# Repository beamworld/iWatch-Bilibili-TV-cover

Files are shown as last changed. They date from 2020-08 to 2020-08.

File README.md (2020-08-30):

# 请注意！！！本项目已迁移至[码云](https://gitee.com/beamworld/iWatch-Bilibili-TV-cover)，github不再更新，最新更新请到码云获取。

# iWatch-Bilibili-TV-cover
	本项目为手表iWatch的Bilibili小电视外壳，目前适用于桌面放置使用。功能如下：

1. 三个按键引出；
2. 耳机通孔引出；
3. Micro USB充电孔引出；
4. 屏幕开孔；

	**上美图~**

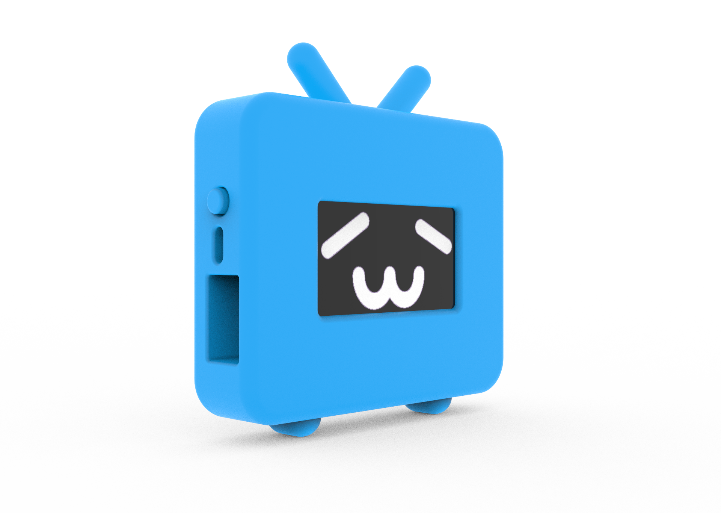
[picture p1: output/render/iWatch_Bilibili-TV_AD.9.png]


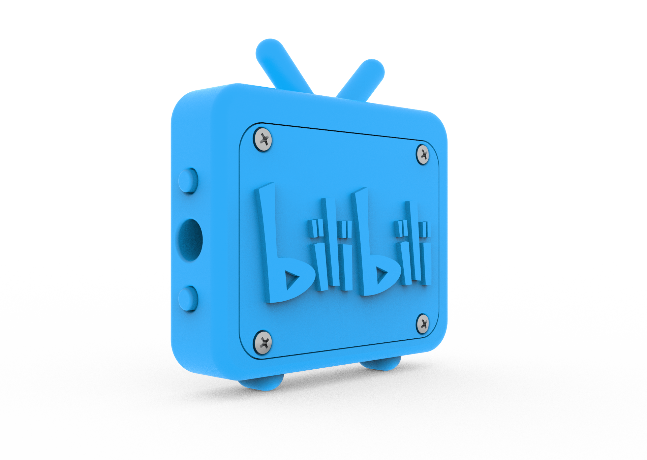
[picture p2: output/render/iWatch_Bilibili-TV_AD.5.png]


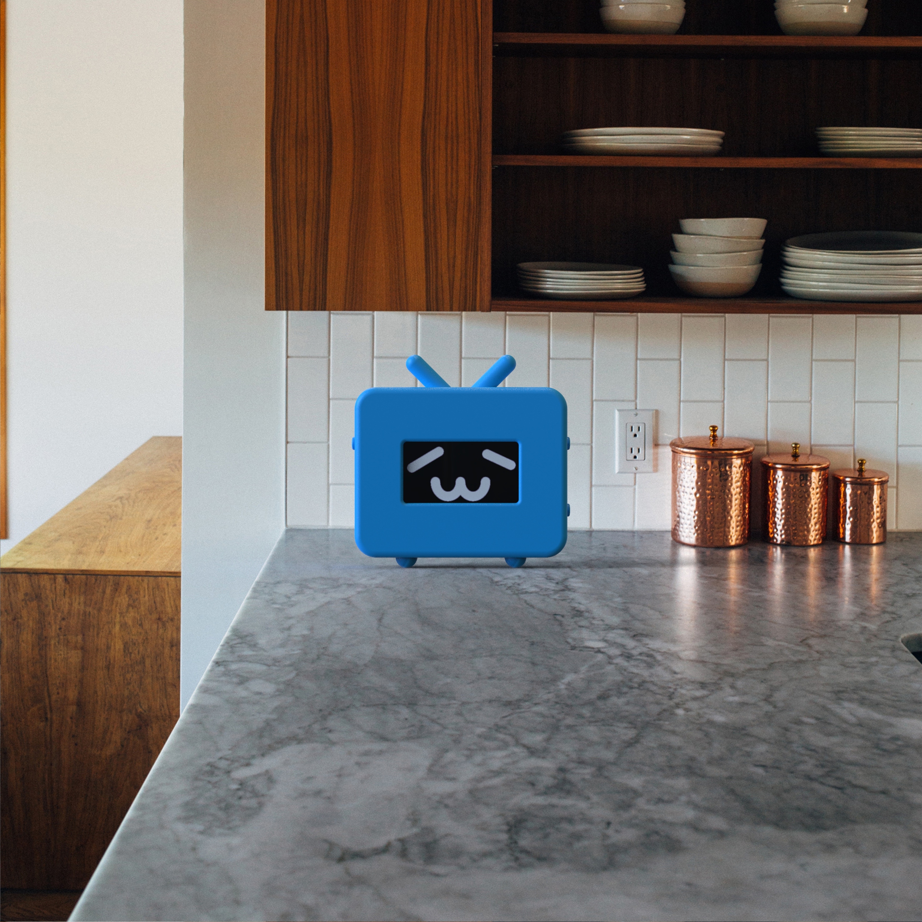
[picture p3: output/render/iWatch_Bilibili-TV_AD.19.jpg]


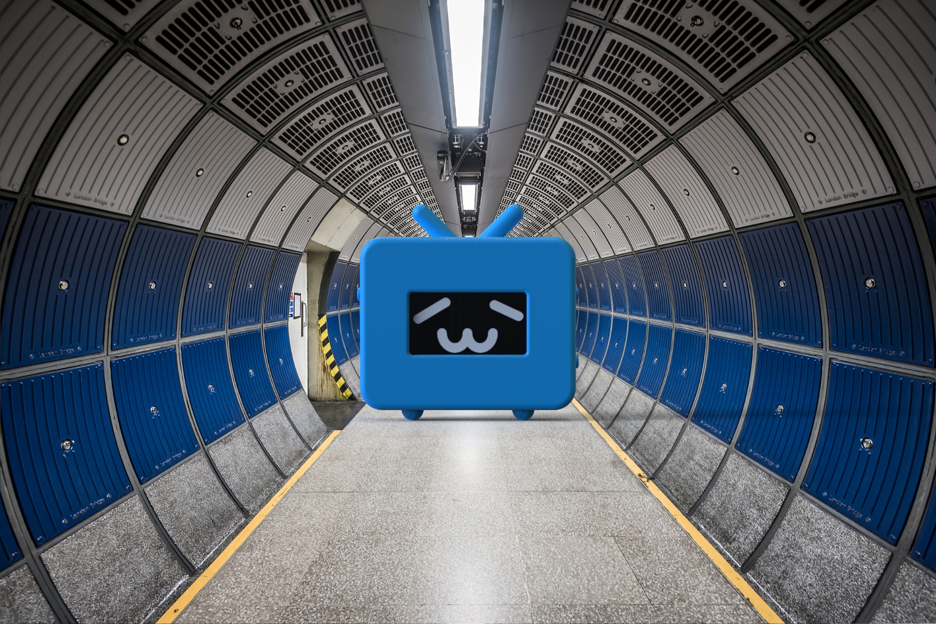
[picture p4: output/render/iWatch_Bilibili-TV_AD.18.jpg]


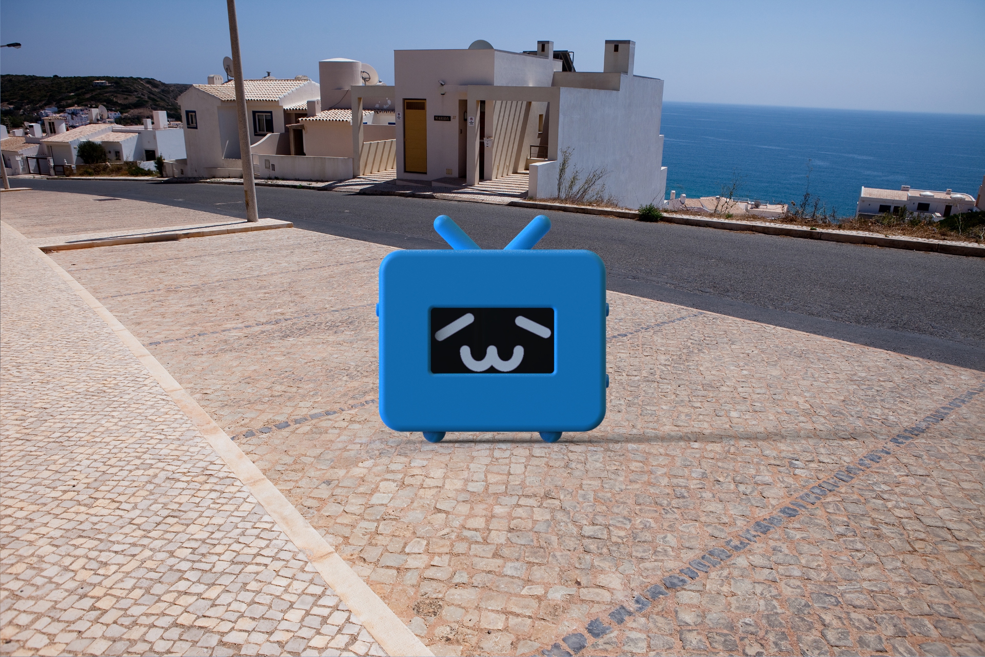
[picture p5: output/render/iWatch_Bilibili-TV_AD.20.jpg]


	又增加了一款手表外壳（Thin-cover），可以佩戴在手上。功能如下：

1. 三个按键引出；
2. 耳机通孔引出；
3. Micro USB充电孔引出；
4. 屏幕开孔；
5. 露出表带安装孔；便于安装表带；
6. 露出充电指示灯和照明灯；
7. 超薄机壳，厚度13mm。

	**上美图~**

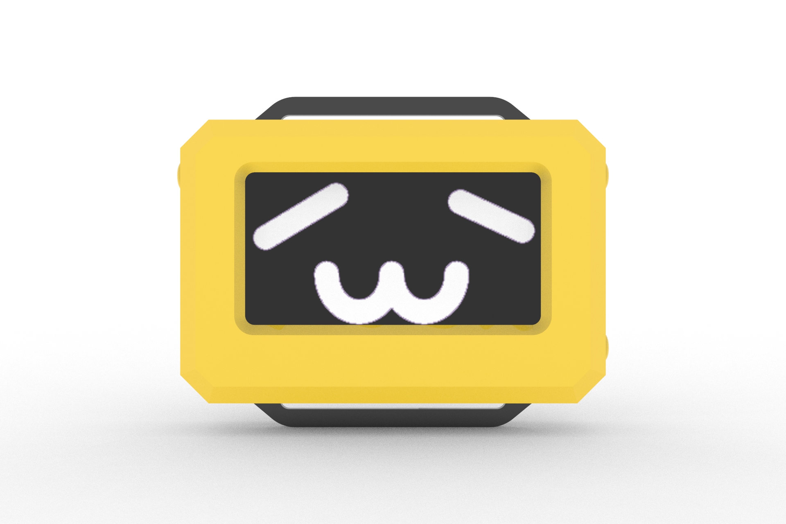
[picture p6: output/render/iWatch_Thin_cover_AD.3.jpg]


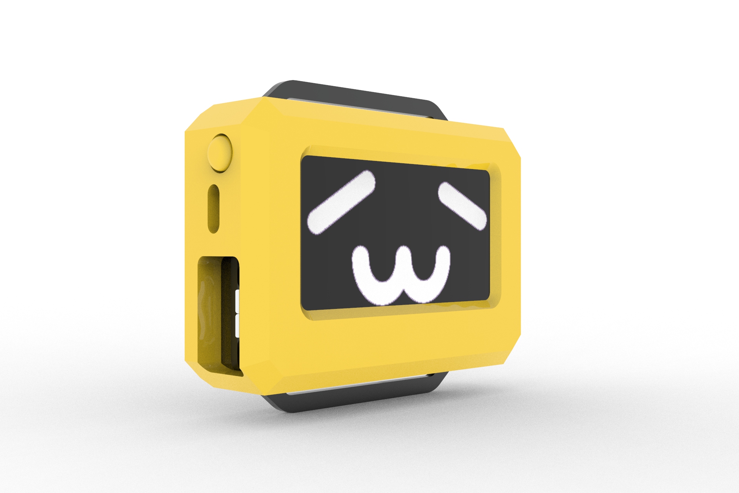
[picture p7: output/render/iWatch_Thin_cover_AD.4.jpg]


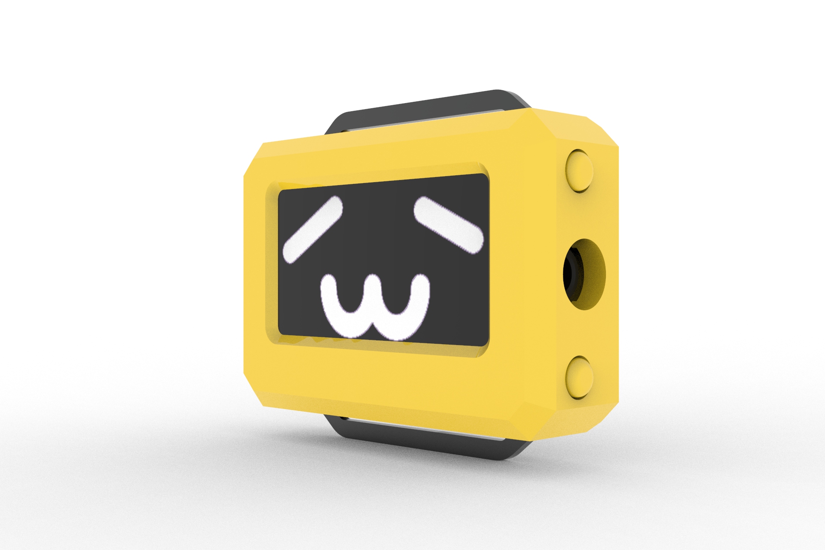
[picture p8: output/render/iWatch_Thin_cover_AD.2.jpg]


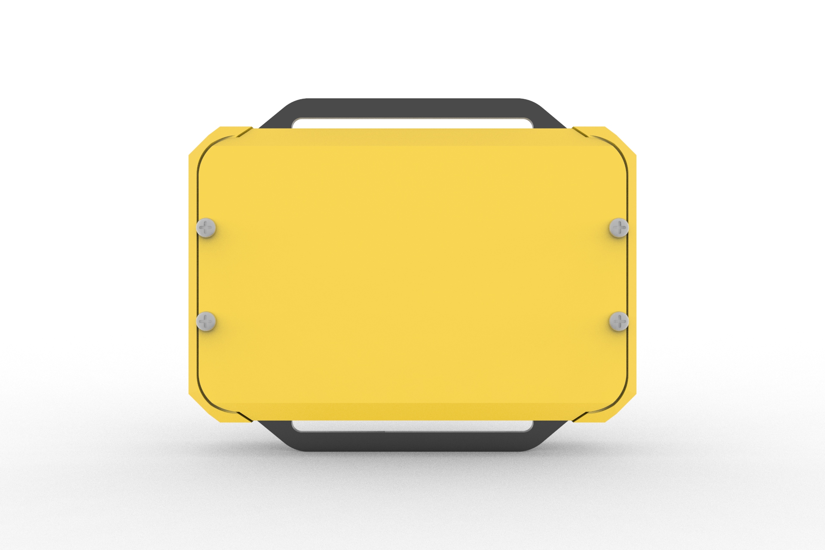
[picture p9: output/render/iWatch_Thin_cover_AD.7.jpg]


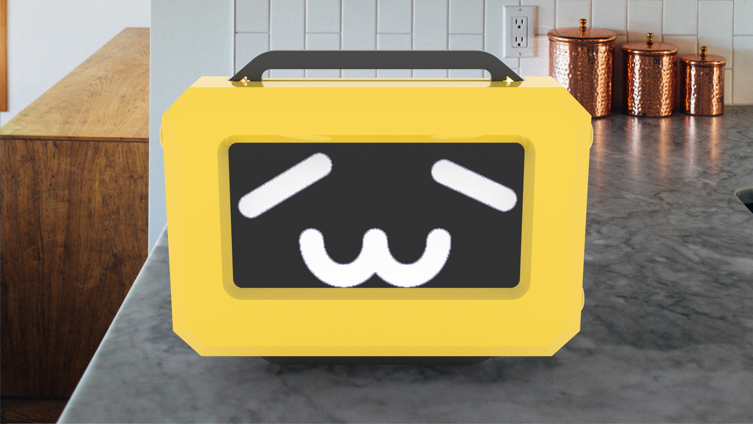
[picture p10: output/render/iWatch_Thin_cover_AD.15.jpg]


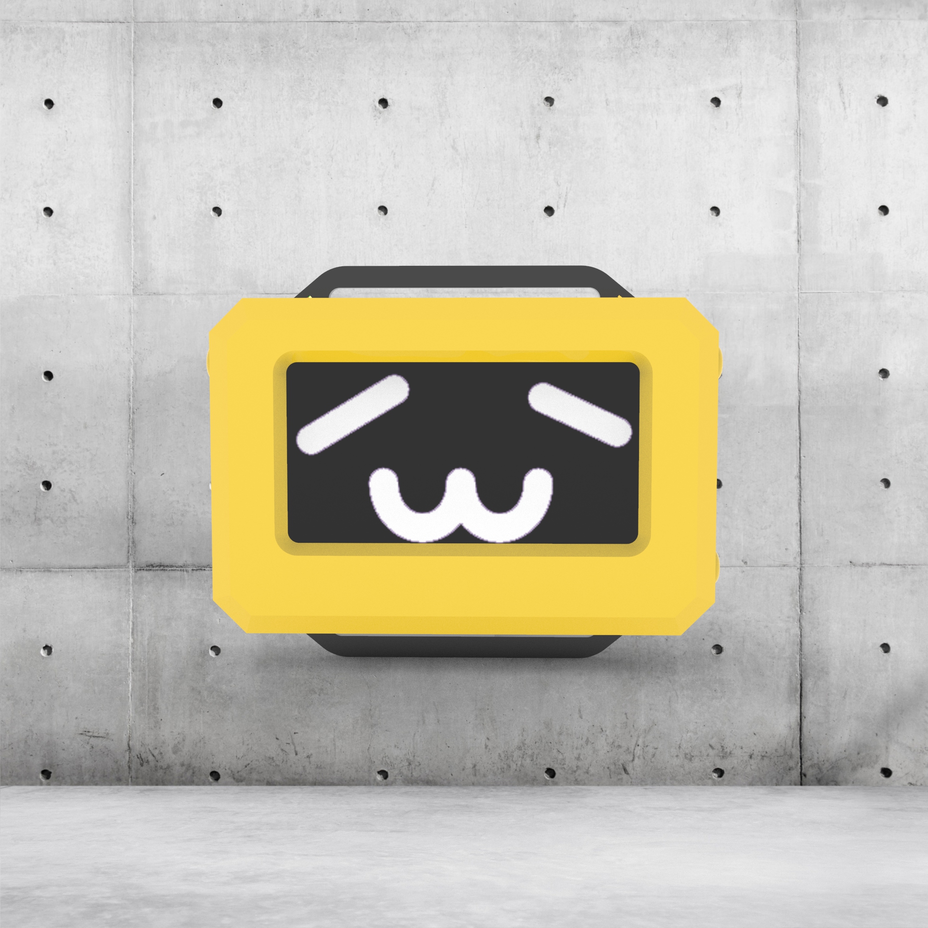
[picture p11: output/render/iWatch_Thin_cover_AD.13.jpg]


## 更新日志

`2020.08.18`

- [x] 测量并绘制iWatch。
- [x] 绘制元器件。
- [x] 组装渲染。
- [x] 获得CXC发来的AD导出STEP。

`2020.08.19`

- [x] 使用STEP重绘板型。
- [x] 组装渲染。
- [x] 绘制part1，part2，part3。
- [x] 修复屏幕露白边问题。
- [x] 修复孔位不对齐问题。
- [x] 修复iWatch-main-board和iWatch-screen-board同时打开会导致板型重载问题。
- [x] 后盖加入Bilibili标识。
- [x] 螺丝改为沉孔设计。
- [x] 整体加厚以保证安全。
- [x] 四边改为等宽增加美观。
- [x] 加入小电视美腿。
- [x] 增大MicroUSB开孔。
- [x] Keyshot渲染出图。
- [x] 加深按键开槽，解决按键太紧问题。
- [x] 加长电视腿，期望解决站不住问题。
- [x] 增大螺丝孔以抵消PLA的热膨胀。
- [x] 加厚前面板，以解决面板太薄露出黑色阴影。

`2020.08.20`

- [x] 增大后盖螺丝孔至2.6以适配更多打印机。
- [x] 新增手戴超薄机壳。

`2020.08.21`

- [x] 加深按键孔。
- [x] 增长按键。
- [x] 内部加入上下倒角，修复因太薄打印出现断开问题。
- [x] 修正小电视外壳充电口不是很准的问题。

## Bilibili-cover 3D打印使用方法

### 第一步：

	直接使用切片软件将[STL模型](https://github.com/beamworld/iWatch-Bilibili-TV-cover/tree/master/output/stl)切片为Gcode，然后再3D打印机上打印即可。需要打印的文件和数量如下。

| 模型名称 | 打印数量 | 用途 |
| :---: | :---: | :---: |
| Bilibili_part1.STL | 1 |  主外壳  |
| Bilibili_part2_cap.STL | 3 | 三个按键 |
| Bilibili_part3.STL | 1 | 后盖 |

**注意：1.Bilibili_part1.STL小电视天线部分需要打印支撑，否者你会获得一个烂电视或者破盒子。**

			**2.打印时不要打印任何类型的平台附着，会很很难刮。**

### 第二步：

	采购螺丝`M2x6盘头十字`四个用于安装后盖。或者你能借到，或者你能把什么拆了都行。

### 第三步：

1. 先把三个按键放到电视上对应孔中。
2. 放入iWatch。
3. 垫上一款减震棉在后盖和电池之间，减震棉你可以在你iWatch的快递盒子里找到，或者你再拆点什么。
4. 拧上4颗螺丝，拧的时候慢慢来，一开始可能不好进入，多蹭蹭~。（螺丝孔使用的是公差配合设计，所以不要整天把螺丝拆下来拧上去，会越来越松！）
5. 享受你的小电视吧。

**#有时间的话会搞一个安装教程----------------------------------------------------明年。**

## 工程指引

**#有时间的话会搞----------------------------------------------------明年。**

## Thin-cover 3D打印使用方法

### 第一步：

	直接使用切片软件将[STL模型](https://github.com/beamworld/iWatch-Bilibili-TV-cover/tree/master/output/stl)切片为Gcode，然后再3D打印机上打印即可。需要打印的文件和数量如下。

| 模型名称 | 打印数量 | 用途 |
| :---: | :---: | :---: |
| Thin_cover_part1.STL | 1 |  主外壳  |
| Thin_cover_part2_cap.STL | 3 | 三个按键 |
| Thin_cover_part3.STL | 1 | 后盖 |

**注意：1.打印时不要打印任何类型的平台附着，会很很难刮。**

### 第二步：

	采购螺丝`M1.2x3盘头十字`四个用于安装后盖。或者你能借到，或者你能把什么拆了都行。

### 第三步：

1. 先把三个按键放到机壳上对应孔中。
2. 放入iWatch。
3. 垫上一款减震棉在后盖和电池之间，减震棉你可以在你iWatch的快递盒子里找到，或者你再拆点什么。
4. 拧上4颗螺丝，拧的时候慢慢来，一开始可能不好进入，多蹭蹭~。（螺丝孔使用的是公差配合设计，所以不要整天把螺丝拆下来拧上去，会越来越松！）
5. 像平常一样安装表带。
6. 享受你的新表壳吧吧。

**#有时间的话会搞一个安装教程----------------------------------------------------明年。**

## 机械开发注意

1. PCB模型各边不是垂直，不确定是绘制PCB时就是如此还是后期导出所致。
2. 由STEP导出的模型转换为sldasm后，iWatch-main-board和iWatch-screen-board同时打开会导致板型重载为先打开的一个，不确定导致问题的原因，但通过导出sldpart解决。

## 友情链接

暂无其他相关开源

**#有时间的话会搞一个Bilibili相关固件给iWatch------------------------------------------明年。**

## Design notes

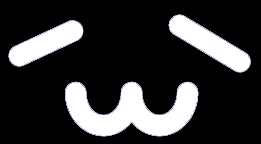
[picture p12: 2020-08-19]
source/image/face_inverted.png

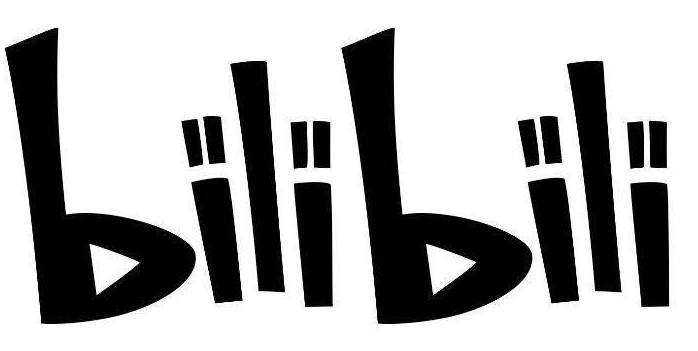
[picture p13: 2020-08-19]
source/image/bilibili.jpg

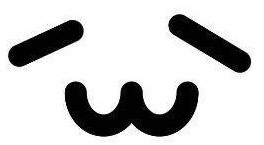
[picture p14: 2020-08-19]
source/image/face.jpg

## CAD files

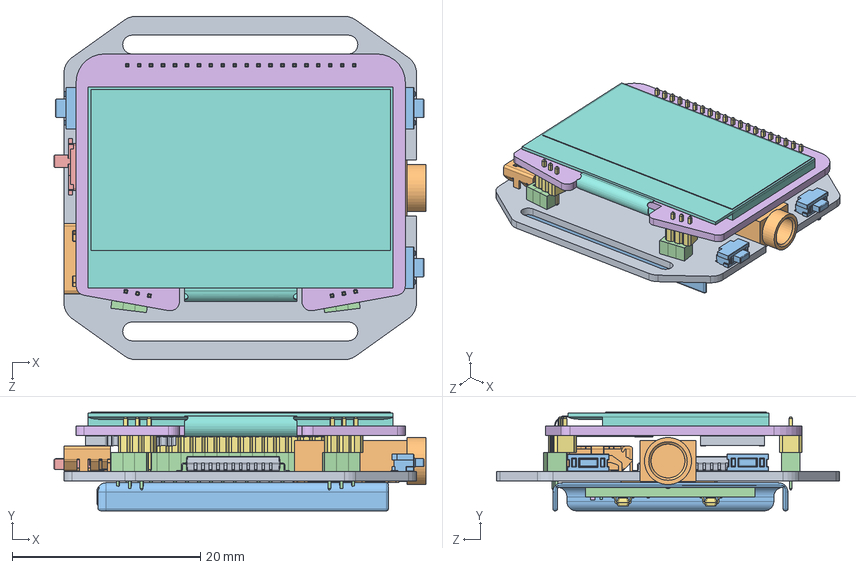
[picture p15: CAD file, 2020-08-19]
assembly/iWatch_unit_measure.SLDASM
39.5 x 10.5 x 36.5 mm
bottom_board
Phone_jack_PJ327A_5P_SMT
Battery_31x25mm_200mAh_3.7V_Li_cell
Battery_protection_board
0201_R
0402_R
SOT23-6 x 2
0201_C
STC51
MicroUSB_SMT
Button_2x4mm_Side_SMT x 3
Female-header_1.27mm_single_2mm-high x 26
Switch_mini_5x3mm_SPDT_Side_SMT
top_board
Male-header_1.27mm_single_2mm-high x 26
1.3inch_OLED
bluetooth_board

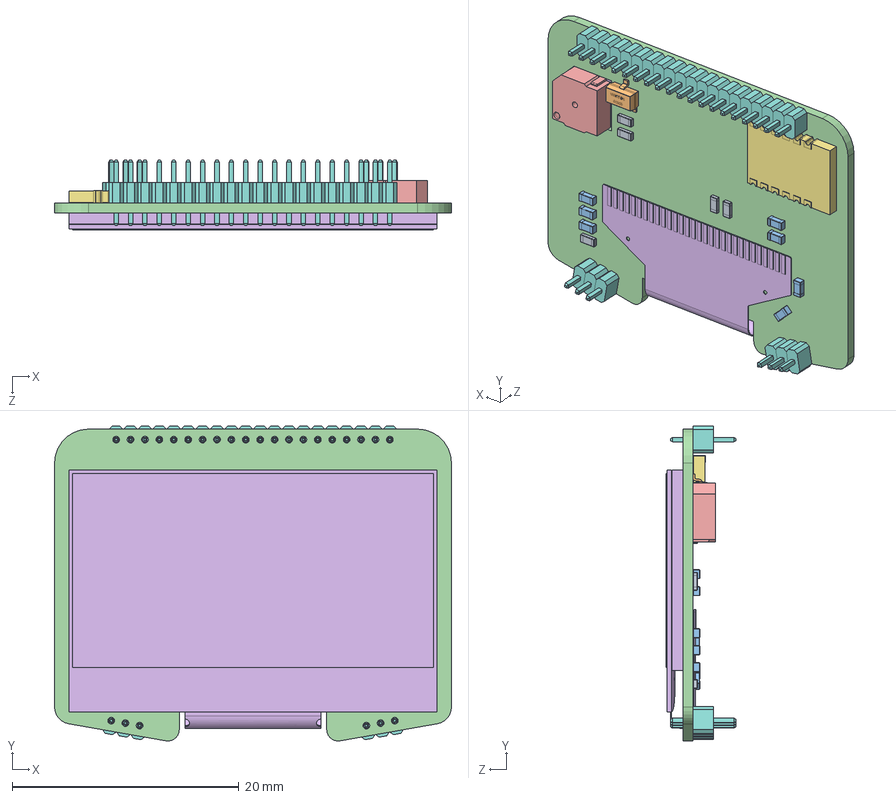
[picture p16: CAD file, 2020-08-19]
partial_assembly/iWatch-screen-board.SLDASM
35.0 x 27.8 x 6.19 mm
RESC1608(0603).step x 5
SOT-23.step
CAPC1608(0603).step x 7
Board.step
Beep_5020_SMT
1.3inch_OLED
bluetooth_board
Male-header_1.27mm_single_2mm-high x 26

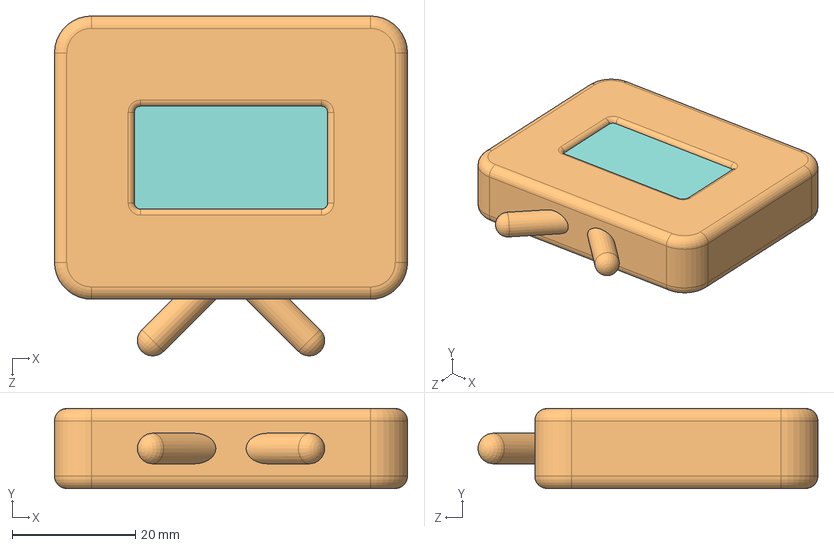
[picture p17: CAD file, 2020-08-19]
assembly/iWatch_Bilibili-TV_measure.SLDASM
57.3 x 13.0 x 55.2 mm
bottom_board
Phone_jack_PJ327A_5P_SMT
Battery_31x25mm_200mAh_3.7V_Li_cell
Battery_protection_board
0201_R
0402_R
SOT23-6 x 2
0201_C
STC51
MicroUSB_SMT
Button_2x4mm_Side_SMT x 3
Female-header_1.27mm_single_2mm-high x 26
Switch_mini_5x3mm_SPDT_Side_SMT
top_board
Male-header_1.27mm_single_2mm-high x 26
1.3inch_OLED
bluetooth_board
Bilibili_part1

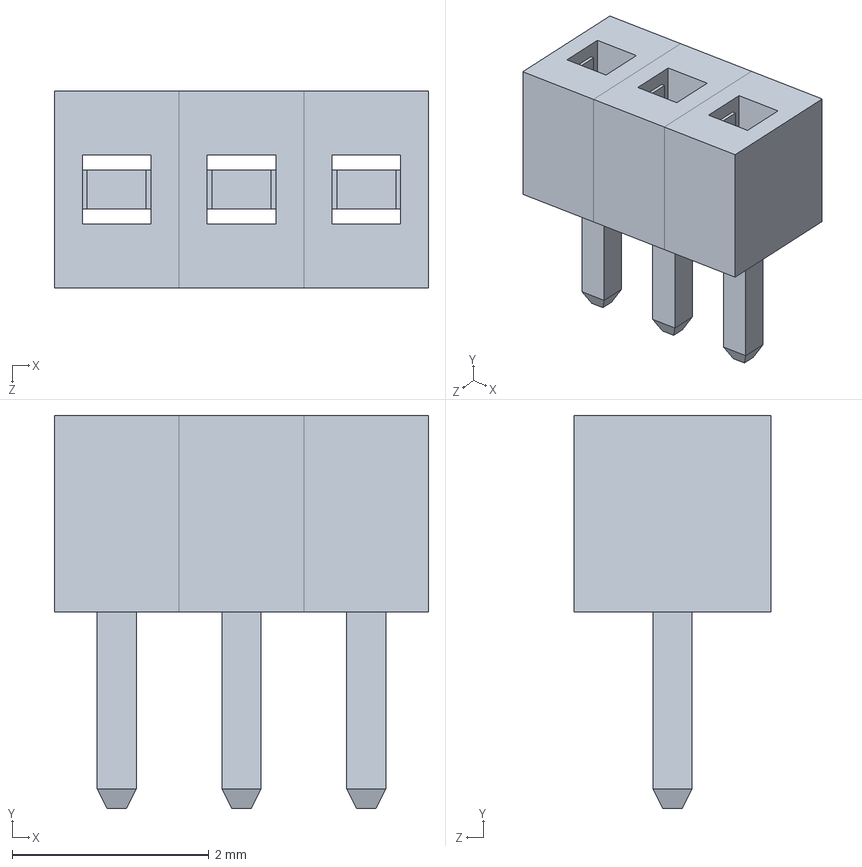
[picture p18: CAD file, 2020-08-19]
component/Header/Female_header_1.27mm_3p_2mm-high.SLDASM
3.81 x 4.00 x 2.00 mm
Female-header_1.27mm_single_2mm-high x 3

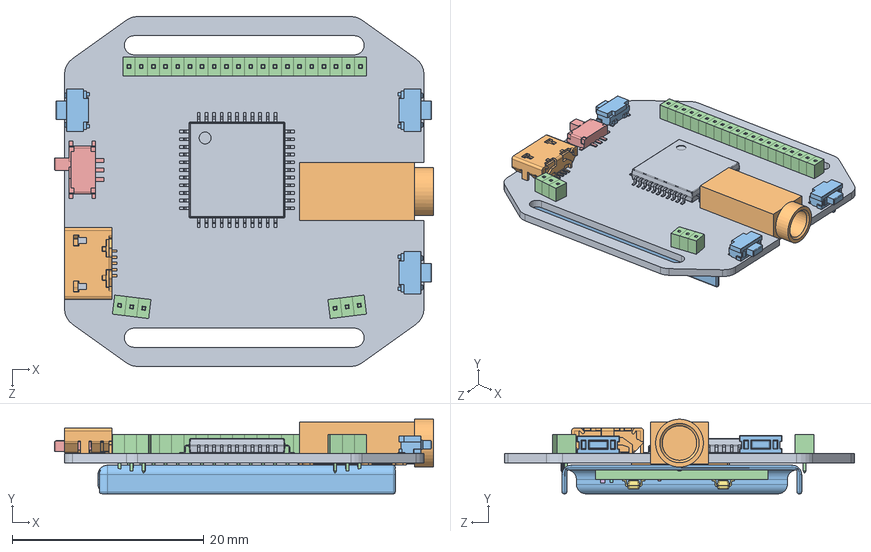
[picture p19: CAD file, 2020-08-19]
partial_assembly/bottom_PCB_measure.SLDASM
39.5 x 7.80 x 36.5 mm
bottom_board
Phone_jack_PJ327A_5P_SMT
Battery_31x25mm_200mAh_3.7V_Li_cell
Battery_protection_board
0201_R
0402_R
SOT23-6 x 2
0201_C
STC51
MicroUSB_SMT
Button_2x4mm_Side_SMT x 3
Female-header_1.27mm_single_2mm-high x 26
Switch_mini_5x3mm_SPDT_Side_SMT

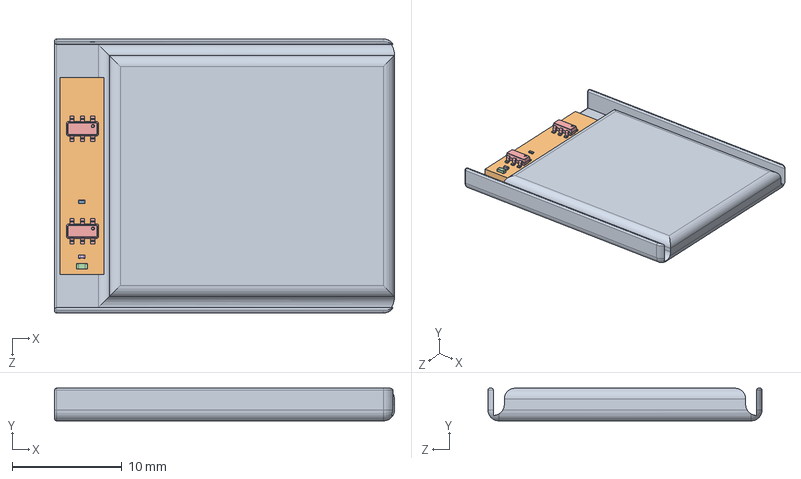
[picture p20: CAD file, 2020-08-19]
component/Battery/Battery_31x25mm_200mAh_3.7V_Li_package.SLDASM
31.0 x 3.00 x 25.0 mm
Battery_31x25mm_200mAh_3.7V_Li_cell
Battery_protection_board
0201_R
0402_R
SOT23-6 x 2
0201_C

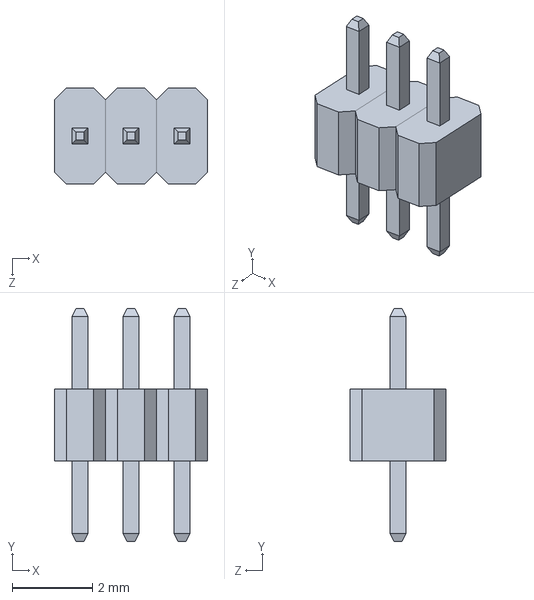
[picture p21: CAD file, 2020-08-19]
component/Header/Male_header_1.27mm_3p_2mm-high.SLDASM
3.81 x 5.80 x 2.40 mm
Male-header_1.27mm_single_2mm-high x 3

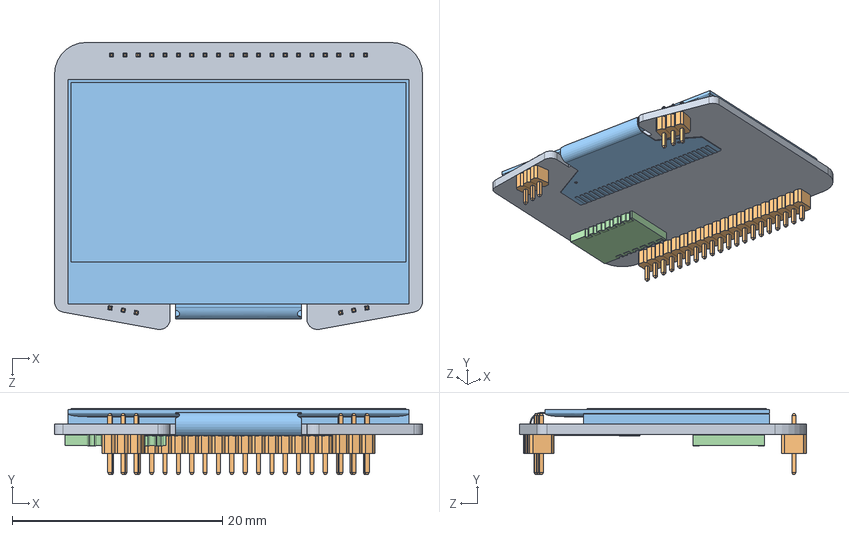
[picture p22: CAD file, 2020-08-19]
partial_assembly/top_PCB_measure.SLDASM
35.0 x 6.30 x 27.3 mm
top_board
Male-header_1.27mm_single_2mm-high x 26
1.3inch_OLED
bluetooth_board

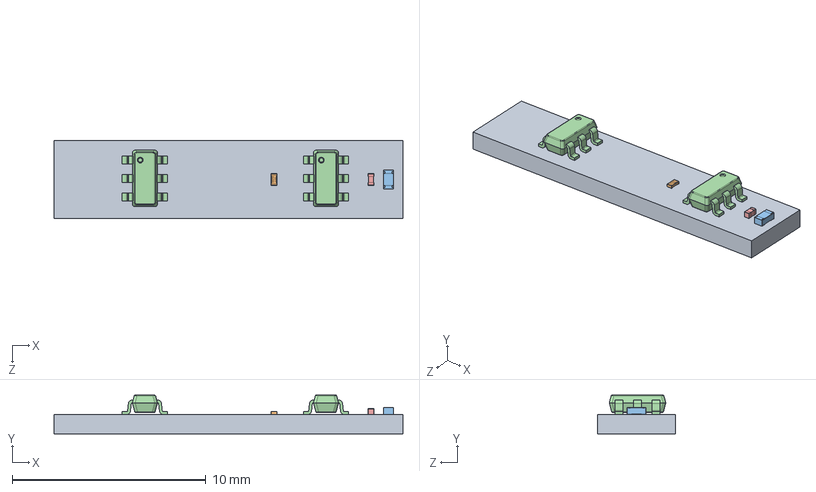
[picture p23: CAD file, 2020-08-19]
component/Battery/Battery_protection_PCB.SLDASM
18.0 x 2.00 x 4.00 mm
Battery_protection_board
0201_R
0402_R
SOT23-6 x 2
0201_C

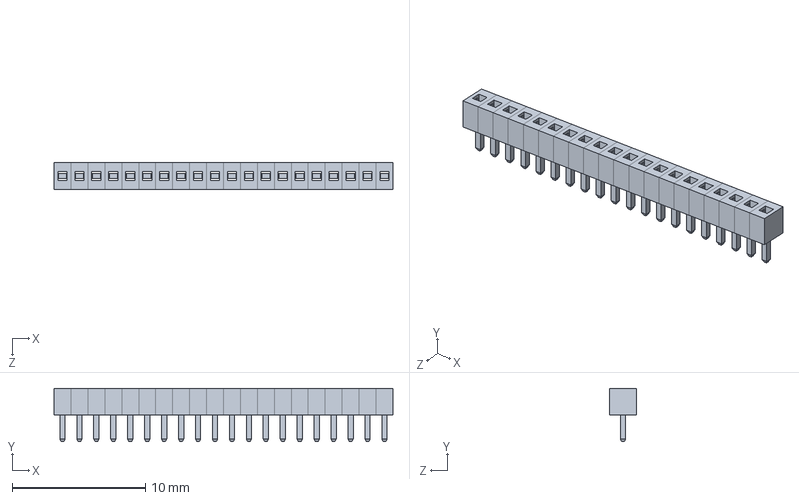
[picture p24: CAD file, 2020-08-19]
component/Header/Female_header_1.27mm_20p_2mm-high.SLDASM
25.4 x 4.00 x 2.00 mm
Female-header_1.27mm_single_2mm-high x 20

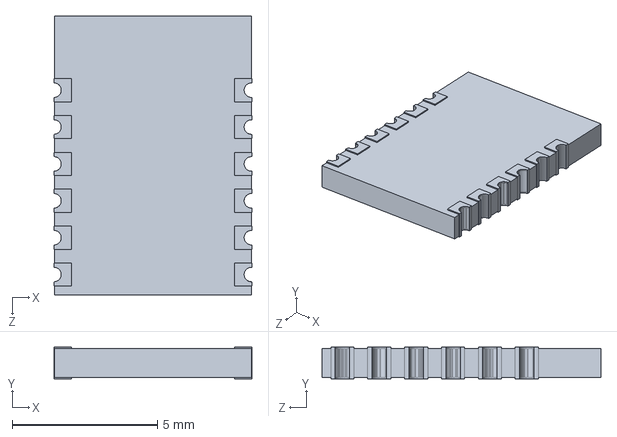
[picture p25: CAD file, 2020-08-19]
partial_assembly/bluetooth_PCB.SLDASM
6.82 x 1.10 x 9.60 mm

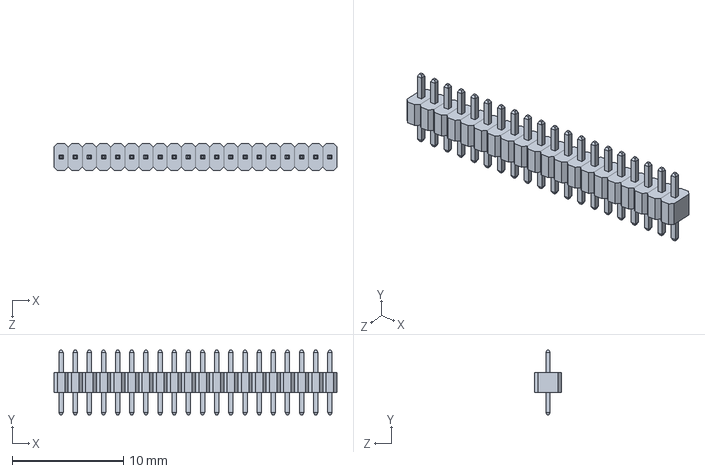
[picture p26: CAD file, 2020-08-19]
component/Header/Male-Header_1.27mm_20p_2mm-high.SLDASM
25.4 x 5.80 x 2.40 mm
Male-header_1.27mm_single_2mm-high x 20

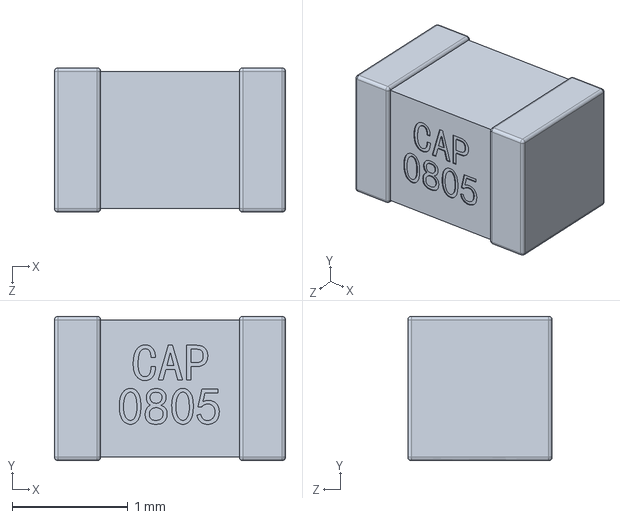
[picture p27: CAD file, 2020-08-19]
component/0805/0805_C.sldprt
2.00 x 1.25 x 1.25 mm

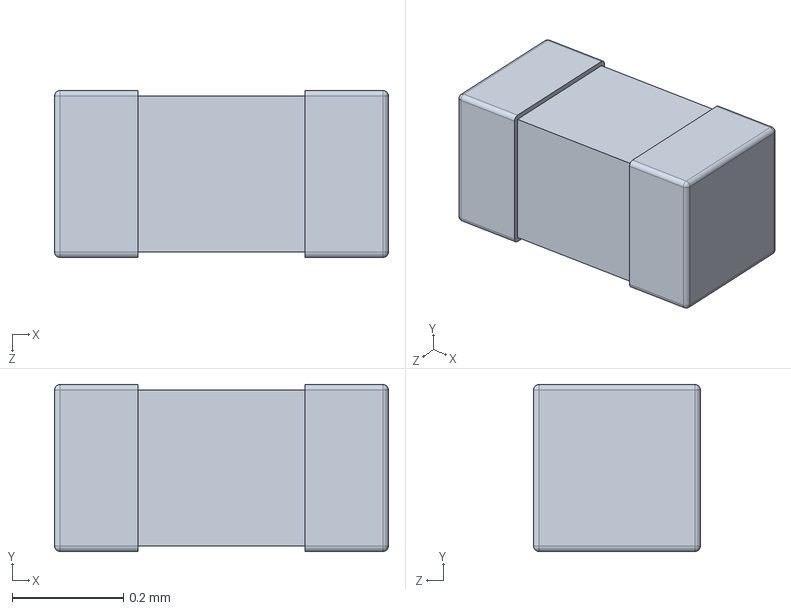
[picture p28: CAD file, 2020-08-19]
component/Battery/0201_C.sldprt
0.6 x 0.3 x 0.3 mm

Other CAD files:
component/Beep/Beep_5020_SMT.SLDPRT
component/Button/Button_2x4mm_Side_SMT.SLDPRT
component/Header/Female-header_1.27mm_single_2mm-high.SLDPRT
component/IC/SOT23-6/SOT23-6.sldprt
component/0805/0805_LED.sldprt
component/0805/0805_R.sldprt
component/Battery/0201_R.SLDPRT
component/Battery/0402_R.sldprt
component/Battery/Battery_31x25mm_200mAh_3.7V_Li_cell.SLDPRT
component/Battery/Battery_protection_board.SLDPRT
component/Battery/SOT23-6.sldprt
component/Header/Male-header_1.27mm_single_2mm-high.SLDPRT
component/IC/STC51/STC51.SLDPRT
component/Jack/Phone_jack_PJ327A_5P_SMT.SLDPRT
component/OLED/1.3inch_OLED.sldprt
component/Switch/Switch_mini_5x3mm_SPDT_Side_SMT.SLDPRT
component/USB/MicroUSB_SMT.sldprt
output/stl/Bilibili_part1.STL
output/stl/Bilibili_part2_cap.STL
output/stl/Bilibili_part3.STL
output/stl/Thin_cover_part1.STL
output/stl/Thin_cover_part2_cap.STL
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

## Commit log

2020-08-19 finish rev1.0
    [Beep_5020_SMT.SLDPRT, Bilibili_part1.SLDPRT, Bilibili_part1.STL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]
2020-08-19 Add component/0805/0805_C.sldprt Add component/0805/0805_LED.sldprt Add component/0805/0805_R.sldprt
    [0805_C.sldprt, 0805_LED.sldprt, 0805_R.sldprt]
2020-08-19 已修改 README.md
2020-08-19 已修改 assembly/iWatch_Bilibili-TV_AD.SLDASM 已修改 special_part/Bilibili_part1.SLDPRT 已修改 special_part/Bilibili_part3.SLDPRT
    [Bilibili_part1.SLDPRT, Bilibili_part3.SLDPRT]
2020-08-20 已修改 README.md 已修改 output/stl/Bilibili_part1.STL 已修改 output/stl/Bilibili_part3.STL 已修改 special_part/Bilibili_part3.SLDPRT
    [Bilibili_part1.STL, Bilibili_part3.SLDPRT, Bilibili_part3.STL]
2020-08-20 add new cover
    [M1.2x3.sldprt, Thin_cover_part1.SLDPRT, Thin_cover_part2_cap.SLDPRT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]
2020-08-20 creat stl
    [Thin_cover_part1.STL, Thin_cover_part2_cap.STL, Thin_cover_part3.STL]
2020-08-21 已修改 README.md 已修改 assembly/iWatch_Thin_cover_AD.SLDASM 已修改 output/stl/Thin_cover_part1.STL 已修改 output/stl/Thin_cover_part2_cap.STL 已修改 special_part/Thin_cover_part1.SLDPRT 已修改 special_part/Thin_cover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
    [Thin_cover_part1.SLDPRT, Thin_cover_part1.STL, Thin_cover_part2_cap.SLDPRT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]
2020-08-21 已修改 README.md 已修改 assembly/iWatch_Bilibili-TV_AD.SLDASM 已修改 output/stl/Bilibili_part1.STL 已修改 special_part/Bilibili_part1.SLDPRT
    [Bilibili_part1.SLDPRT, Bilibili_part1.STL]
